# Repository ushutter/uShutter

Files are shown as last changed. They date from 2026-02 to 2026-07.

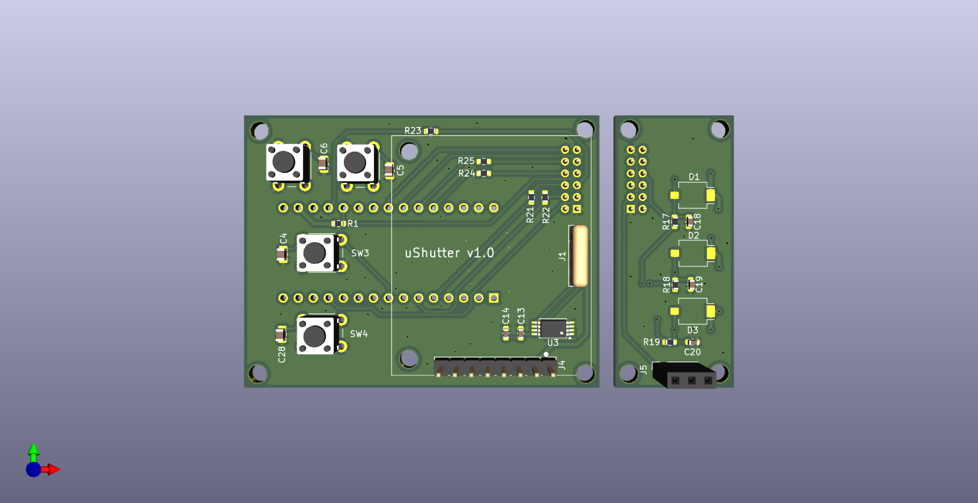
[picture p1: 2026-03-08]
Hardware/1.0.3/3D reveiw v1.0.3.png

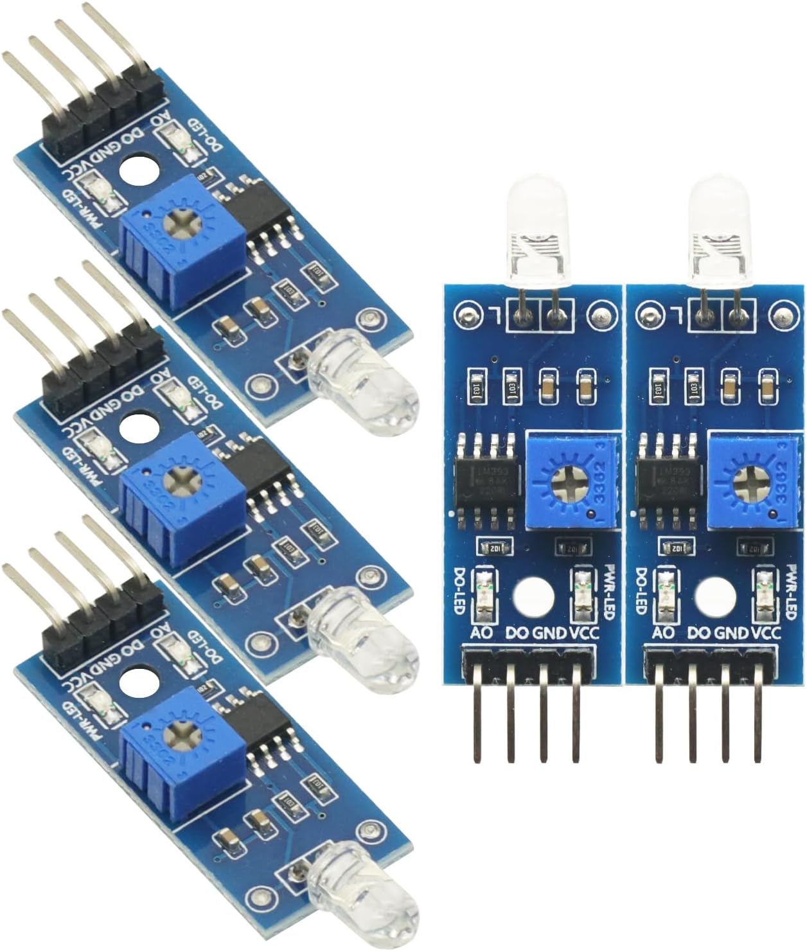
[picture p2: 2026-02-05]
Hardware/Preliminary Version/LM393_LED.jpg

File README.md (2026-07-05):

# uShutter

Introduction video on Youtube:
uShutter (https://www.youtube.com/watch?v=xxOWjmqUMyQ)
uShutter is an open, reproducible shutter timing specification and implementation, focused on time-domain shutter speed and curtain travel measurement.

uShutter provides a firmware and multiple reference hardware interface implementation for measuring:
* shutter exposure time and stability
* curtain travel time and stability

It uses pure time-domain signals from different optical sensors. Measurement accuracy highly depends on the sensors selected and PCB board manufacturing quality.

## What uShutter Is
* An open measurement core for shutter timing
* A reference implementation for single- and dual-sensor setups
* A stable timing interface others can implement or extend
* Suitable for DIY, education, analysis, and experimentation

## Core Capabilities (Open Scope)
uShutter includes the following open-source capabilities:
### Shutter Timing
* Optical trigger–based event capture
* Microsecond-resolution timestamps
* Direction-independent logic
### Single-Sensor Measurement
* Exposure duration measurement
* Multi-shot repeatability analysis
### Dual-Sensor Curtain Analysis
* Curtain travel time
* Relative curtain speed

## Hardware Philosophy
uShutter is designed to work with:
* Arduino / ATmega328P MCUs
* Simple optical sensors (e.g. LM393-based comparators)
* No specific sensor type, threshold method, or light source is assumed by the interface.

## Project Structure
/Firmware    Code implementation 

/Hardware    Reference schematics and layouts

[Theory, usage, and build notes](https://ushutter90.wordpress.com/how-to/)

## License
Firmware: Apache License 2.0

Hardware designs: CERN-OHL-S

This project is open by design and intent.

## Status
uShutter is under active development.

Interface stability and clarity take priority over feature expansion.

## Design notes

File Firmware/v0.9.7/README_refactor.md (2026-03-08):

# uShutter refactor notes (WIP)

This project has been split from a monolithic `.ino` into multiple translation units to improve maintainability and avoid Arduino preprocessor issues.

## File responsibilities

- `uShutter_v0_9_5_refactor_wip.ino`
  - Minimal Arduino entry placeholder.
  - Keep this tiny; do not put logic here.

- `app.cpp`
  - Main orchestration/state machine.
  - Setup/loop flow.
  - Measurement logic, stability calculation, button handling.
  - Calls into display and capture modules.

- `Display.h` / `Display.cpp`
  - OLED/UI rendering only.
  - Splash, error screen, realtime views, table view.
  - Should avoid business logic changes where possible.

- `Capture.h` / `Capture.cpp`
  - Interrupt attach/detach.
  - ISR edge capture and capture-complete signaling.
  - No UI rendering.

- `AppShared.h`
  - Shared enums/types/constants used across modules.
  - Single source for common declarations (`MeasureMode`, `SensorFrontend`, `TravelDirection`, `EdgeTimes`, sensor pin constants, etc.).

## Why this structure

Arduino `.ino` files are auto-preprocessed (prototype generation), which can break during aggressive function splitting. Keeping logic in `.cpp/.h` avoids those fragile transforms.

## Safe edit rules

1. **Prefer editing `.cpp/.h`, not `.ino`.**
2. **After each micro-change, compile immediately.**
3. **Keep cross-module contracts explicit:**
   - Put shared enums/structs in `AppShared.h`.
   - Keep module APIs in `Display.h` / `Capture.h`.
4. **Avoid duplicate type definitions** across modules.
5. **If introducing new shared state**, declare in `app.cpp`, reference via `extern` in module `.cpp` files.

## Compile check

Reference compile command:

```bash
arduino-cli compile --fqbn arduino:avr:nano /Users/leonyao/Documents/uShutter_v0_9_5_refactor_wip
```

Latest known good result (at time of writing):
- Flash: ~26,346 bytes (85%)
- RAM: ~1,396 bytes (68%)

## Next recommended refactor steps

1. Replace remaining broad `extern` usage with a thinner shared context struct (optional).
2. Move frontend detection helpers into a dedicated `Frontend.cpp/.h` (optional).
3. Add a small host-side smoke checklist (compile + key behavior sanity list).

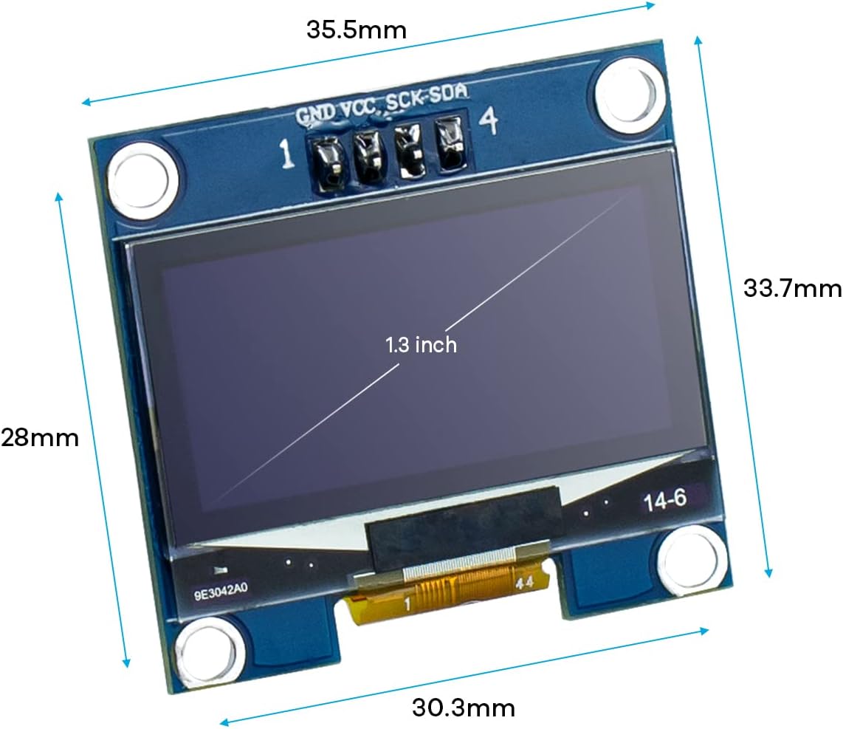
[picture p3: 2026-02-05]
Hardware/Preliminary Version/OLED.jpg

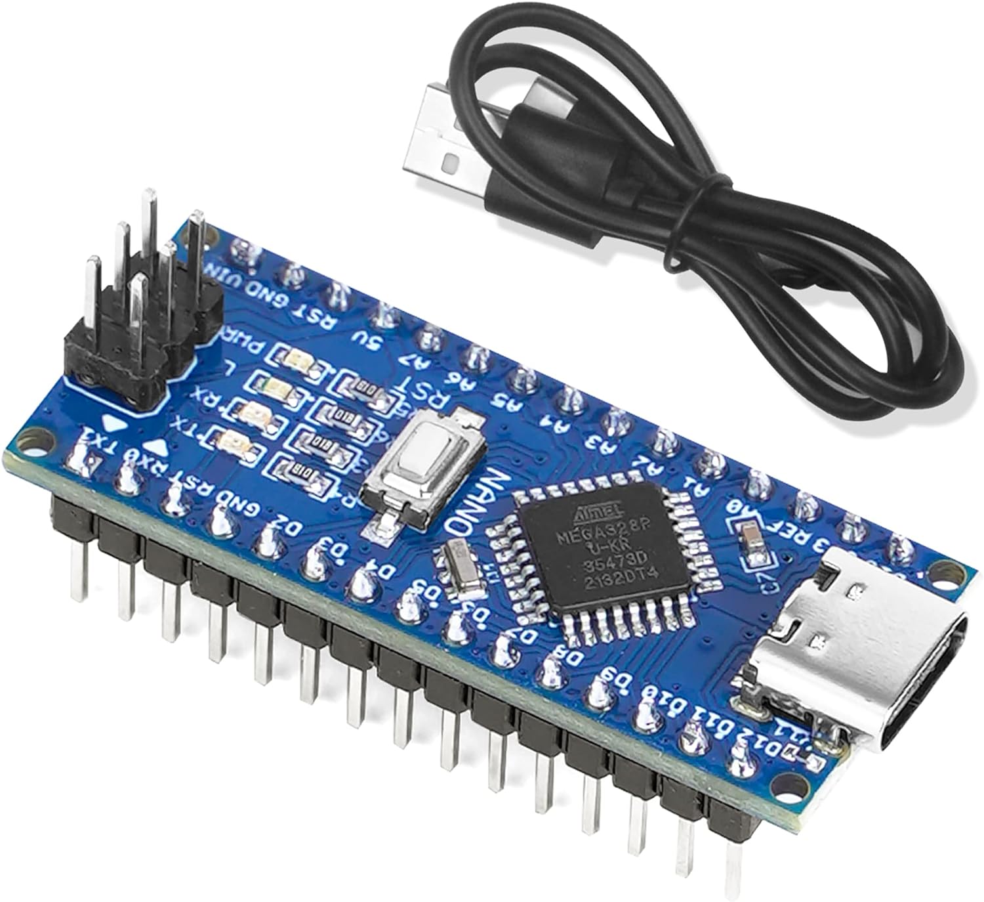
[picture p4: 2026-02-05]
Hardware/Preliminary Version/Arduino nano.jpg

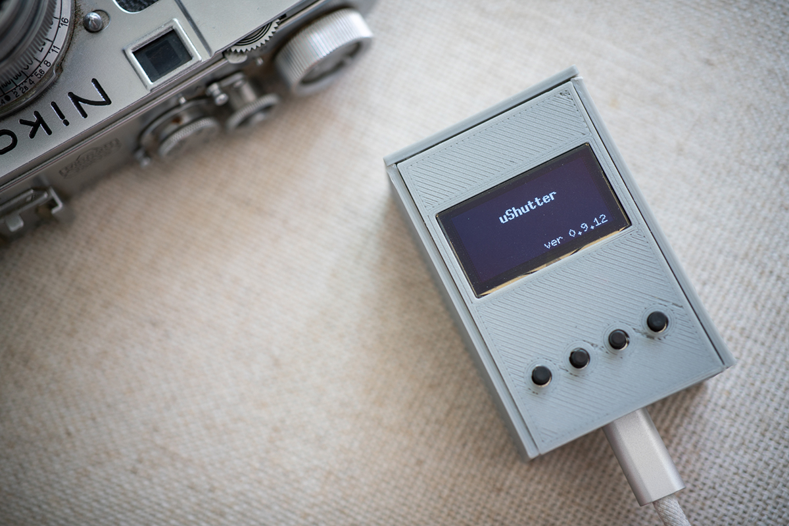
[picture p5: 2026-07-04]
Firmware/uShutter3.jpg

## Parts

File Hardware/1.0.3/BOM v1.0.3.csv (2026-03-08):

Id | Designator | Footprint | Quantity | Designation | Supplier and ref
1 | C6,C28,C5,C4 | C_0805_2012Metric | 4 | 10uF
2 | C14,C1,C16 | C_0603_1608Metric | 3 | 1uF
3 | R18,R19,R17 | R_0603_1608Metric | 3 | 100
4 | U3 | TSSOP-8_4.4x3mm_P0.65mm | 1 | AT24CS08-XHM
5 | D1,D3,D2 | Osram_BPW34S-SMD | 3 | BPW34-SMD
6 | J1 | R_Array_SIP4 | 1 | OLED
7 | R1 | R_0603_1608Metric | 1 | 100k
8 | R24,R25 | R_0603_1608Metric | 2 | 0
9 | R23,R22,R21,R28,R27,R29,R26 | R_0603_1608Metric | 7 | 22
10 | J5 | PinSocket_1x03_P2.54mm_Vertical | 1 | Light
11 | C13,C2,C17,C22 | C_0603_1608Metric | 4 | 0.1uF
12 | SW2,SW3,SW1,SW4 | SW_PUSH_6mm | 4 | SW_Push
13 | C19,C18,C20 | C_0603_1608Metric | 3 | 10pF or NC
14 | J4 | PinHeader_1x08_P2.54mm_Vertical | 1 | SPI
15 | C10,C9,C8 | C_0603_1608Metric | 3 | 10pF
16 | J3,J9 | ushutter | 2 | Conn_01x12
17 | R5,R6,R4 | R_0603_1608Metric | 3 | 220K
18 | R7,R8 | R_0603_1608Metric | 2 | 4.7K_or_depends_on_OLED
19 | R2 | R_0603_1608Metric | 1 | 1K
20 | A1 | Arduino_Nano | 1 | Arduino_Nano_v3.x
21 | U1 | SSOP-14_5.3x6.2mm_P0.65mm | 1 | 74HC14

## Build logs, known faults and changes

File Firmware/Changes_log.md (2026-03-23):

uShutter change summary: uShutter_v0_9_5_refactor_wip -> uShutter_v0_9_6
Generated: Fri Feb 27 22:52:08 PST 2026

== Files only in each folder ==
Only in v0_9_5_refactor_wip:
uShutter_v0_9_5_refactor_wip.ino

Only in v0_9_6:
uShutter_v0_9_6.ino

== High-level functional differences ==
- BTN_RESET pin changed to D4 in v0_9_6 (from D6 in refactor_wip at latest baseline).
- BTN_MODE pin remains D5, but behavior changed in v0_9_6:
  * short click: toggle sensor s1/s2 (only when FE=Dual and mode=SINGLE)
  * long hold: toggle mode DUAL<->SINGLE
- BTN_RESET behavior in v0_9_6 is single-click reset only.
- Startup splash flow remains 3-stage with 2.0s each splash.

== Key code-level diff snippets (app.cpp / Display.cpp / headers) ==
--- /Users/leonyao/Documents/uShutter/uShutter_v0_9_5_refactor_wip/app.cpp	2026-02-27 22:16:06
+++ /Users/leonyao/Documents/uShutter/uShutter_v0_9_6/app.cpp	2026-02-27 22:44:57
@@ -11,7 +11,7 @@
 // =================================================
 // Version
 // =================================================
-#define VERSION_STR "ver 0.9.5"
+#define VERSION_STR "ver 0.9.6"
 #define NAME "uShutter"
 #define SLOGAN ""
 
@@ -21,7 +21,8 @@
 #define MIN_VALID_EXPOSURE 1000     // Minimum valid exposure time (us)
 #define MAX_VALID_EXPOSURE 1500000  // Maximum valid exposure time (us)
 
-#define BTN_RESET 5            // Reset button pin (active-low)
+#define BTN_RESET 4            // Reset button pin (active-low)
+#define BTN_MODE 5
 #define BTN_DEBOUNCE_MS 50     // Button debounce time (ms)
 #define BTN_LONGPRESS_MS 1200  // Long press threshold (ms)
 
@@ -133,8 +134,9 @@
 volatile EdgeTimes s1 = { 0, 0, false };
 
 // Helpers for SINGLE mode sensor routing
+uint8_t single_mode_sensor = SINGLE_MODE_SENSOR;  // runtime: 1->s1, 2->s2
 bool singleUsesS1() {
-  return (SINGLE_MODE_SENSOR == 1);
+  return (single_mode_sensor == 1);
 }
 
 volatile bool new_result = false;
@@ -483,40 +485,71 @@
 bool handleResetButton() {
   static bool last_level = true;  // true = released (pull-up)
   static unsigned long t_last_change = 0;
-  static unsigned long t_pressed = 0;
-  static bool long_handled = false;
 
   bool level = digitalRead(BTN_RESET);  // HIGH released, LOW pressed
   unsigned long now_ms = millis();
 
   if (level != last_level) {
-    if (now_ms - t_last_change < BTN_DEBOUNCE_MS) {
-      return true;
+    if (now_ms - t_last_change < BTN_DEBOUNCE_MS) return true;
+    t_last_change = now_ms;
+    last_level = level;
+
+    // single click on release => reset
+    if (level) {
+      resetMeasurement();
     }
+    return true;
+  }
+  return false;
+}
+
+// BTN_MODE:
+// - Single click: toggle mode (DUAL<->SINGLE)
+// - Double click (only FE Dual + SINGLE mode): toggle single sensor s1/s2
+bool handleModeButton() {
+  static bool last_level = true;
+  static unsigned long t_last_change = 0;
+  static unsigned long t_pressed = 0;
+  static bool long_handled = false;
+
+  bool level = digitalRead(BTN_MODE);
+  unsigned long now_ms = millis();
+
+  bool sensor_toggle_enabled = (sensor_frontend == FRONTEND_FE1_DUAL && measure_mode == MODE_SINGLE_EXPOSURE);
+
+  if (level != last_level) {
+    if (now_ms - t_last_change < BTN_DEBOUNCE_MS) return true;
     t_last_change = now_ms;
     last_level = level;
 
     if (!level) {
+      // pressed
       t_pressed = now_ms;
       long_handled = false;
     } else {
+      // released
       if (!long_handled) {
-        resetMeasurement();
+        // short click: toggle sensor s1/s2 (only when FE=Dual and mode=SINGLE)
+        if (sensor_toggle_enabled) {
+          single_mode_sensor = (single_mode_sensor == 1) ? 2 : 1;
+          disableLightISR();
+          displayModeSplash();
+          delay(600);
+          resetMeasurement();
+        }
       }
     }
     return true;
   }
 
+  // long press: toggle mode
   if (!level && !long_handled) {
     if (now_ms - t_pressed >= BTN_LONGPRESS_MS) {
       long_handled = true;
-
       measure_mode = (measure_mode == MODE_DUAL_CURTAIN) ? MODE_SINGLE_EXPOSURE : MODE_DUAL_CURTAIN;
-
       disableLightISR();
       displayModeSplash();
       delay(600);
-
       resetMeasurement();
       return true;
     }
@@ -525,6 +558,7 @@
   return false;
 }
 
+
 // =================================================
 // SETUP
 // =================================================
@@ -540,6 +574,7 @@
 
   configureSensorFrontend();
   pinMode(BTN_RESET, INPUT_PULLUP);
+  pinMode(BTN_MODE, INPUT_PULLUP);
 
   u8g2.begin();
 
@@ -570,6 +605,7 @@
 // =================================================
 void loop() {
   handleResetButton();
+  handleModeButton();
 
   if (ui_state == UI_ERROR) {
     displayErrorCode(error_code);

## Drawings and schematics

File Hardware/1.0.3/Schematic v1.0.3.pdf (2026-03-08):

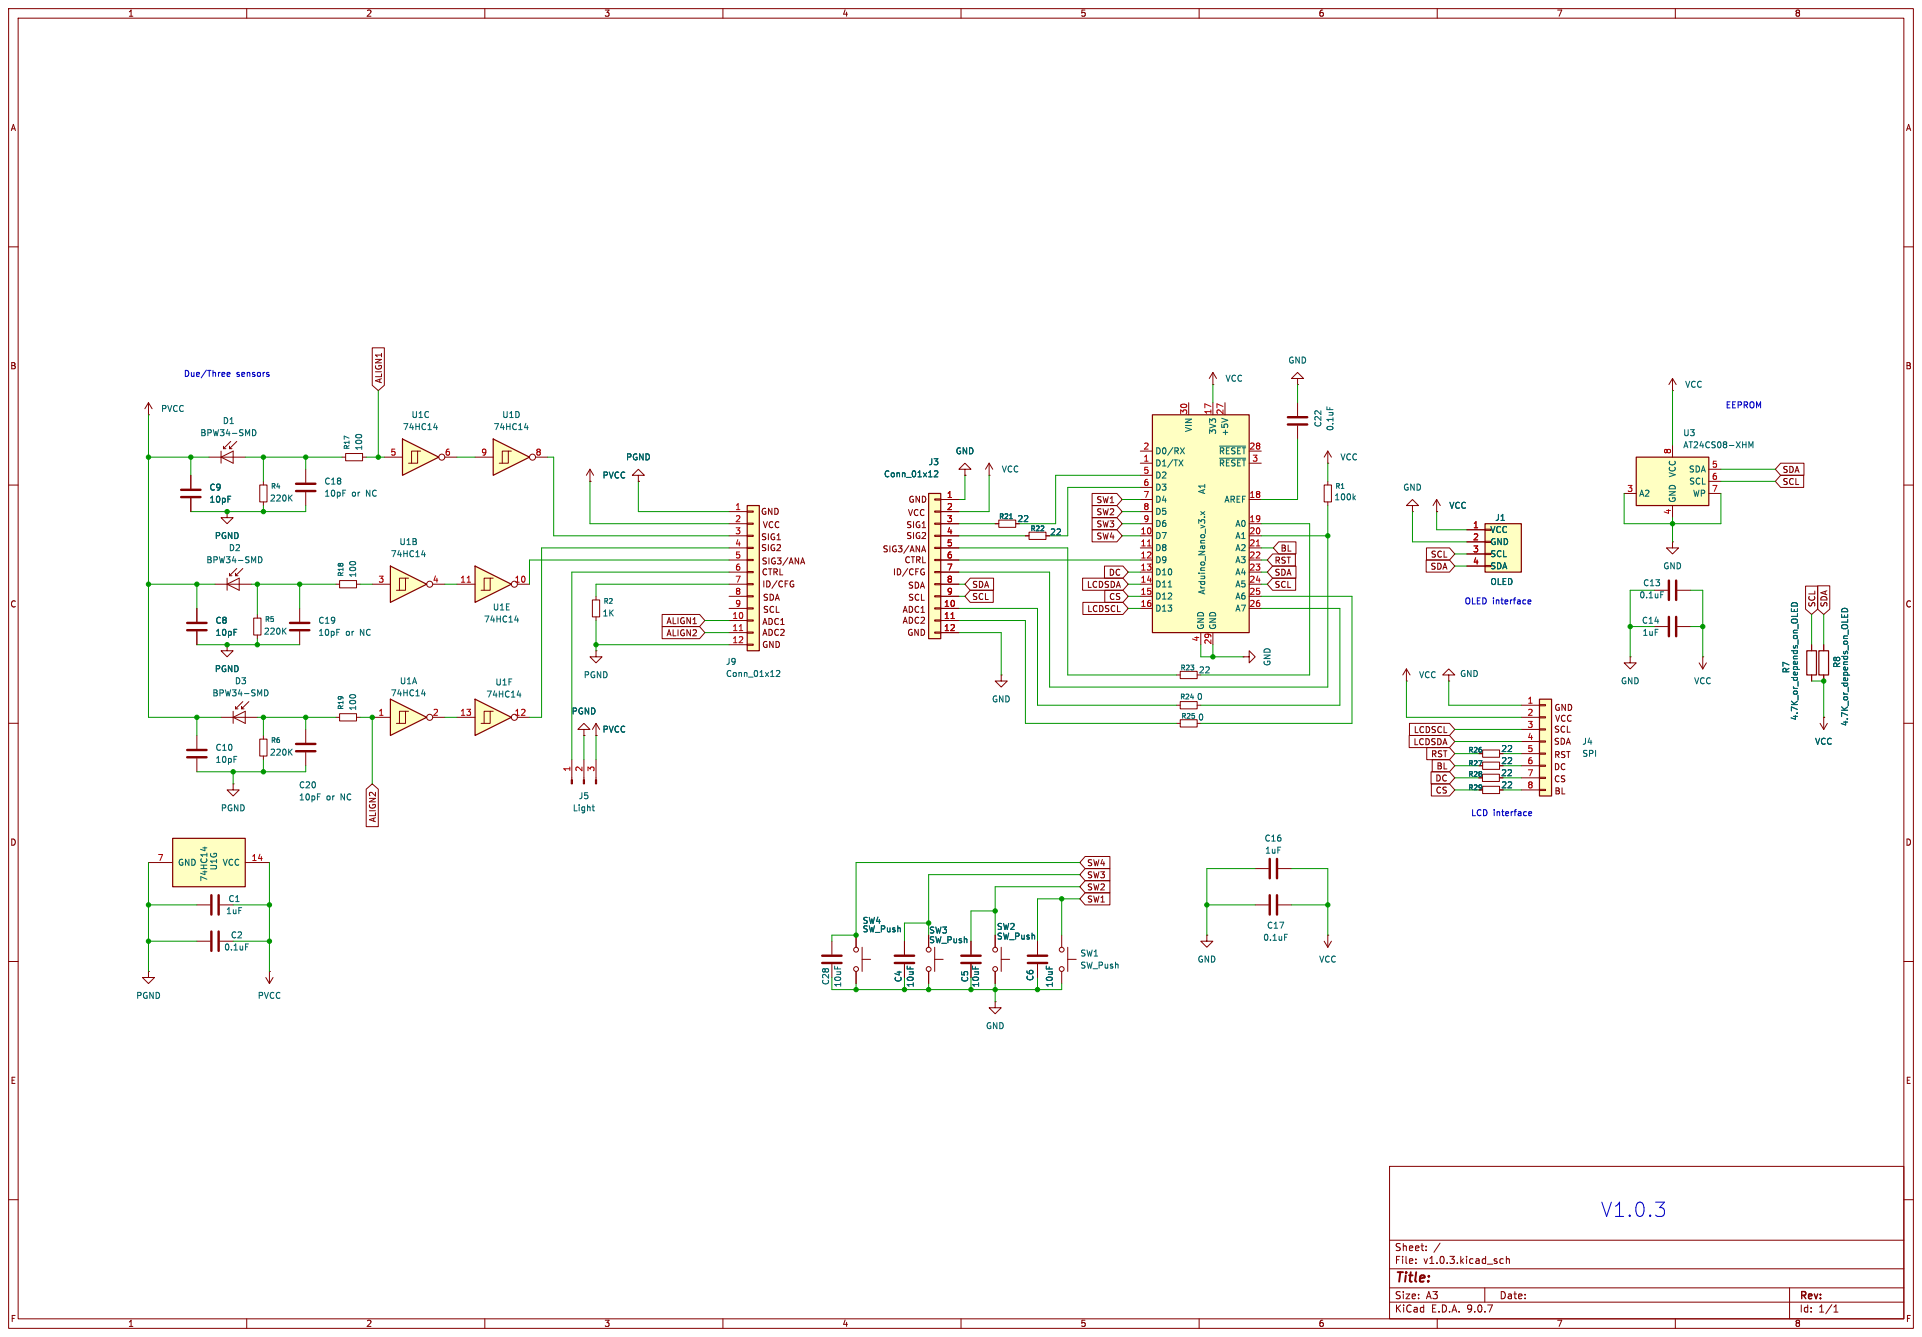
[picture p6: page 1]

Id: 1/1 Title: File: v1.0.3.kicad_sch Sheet: /

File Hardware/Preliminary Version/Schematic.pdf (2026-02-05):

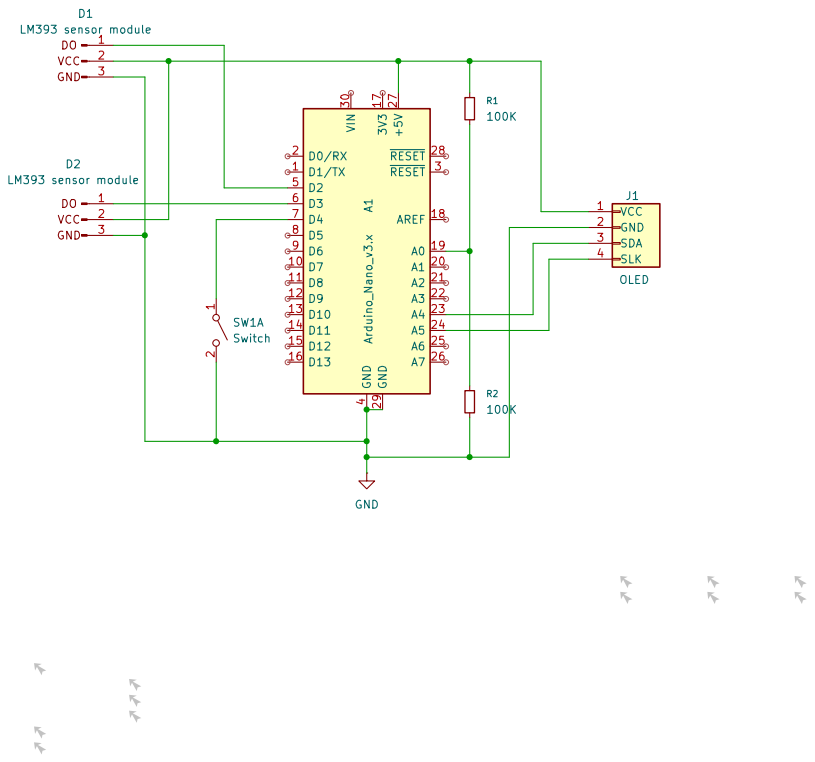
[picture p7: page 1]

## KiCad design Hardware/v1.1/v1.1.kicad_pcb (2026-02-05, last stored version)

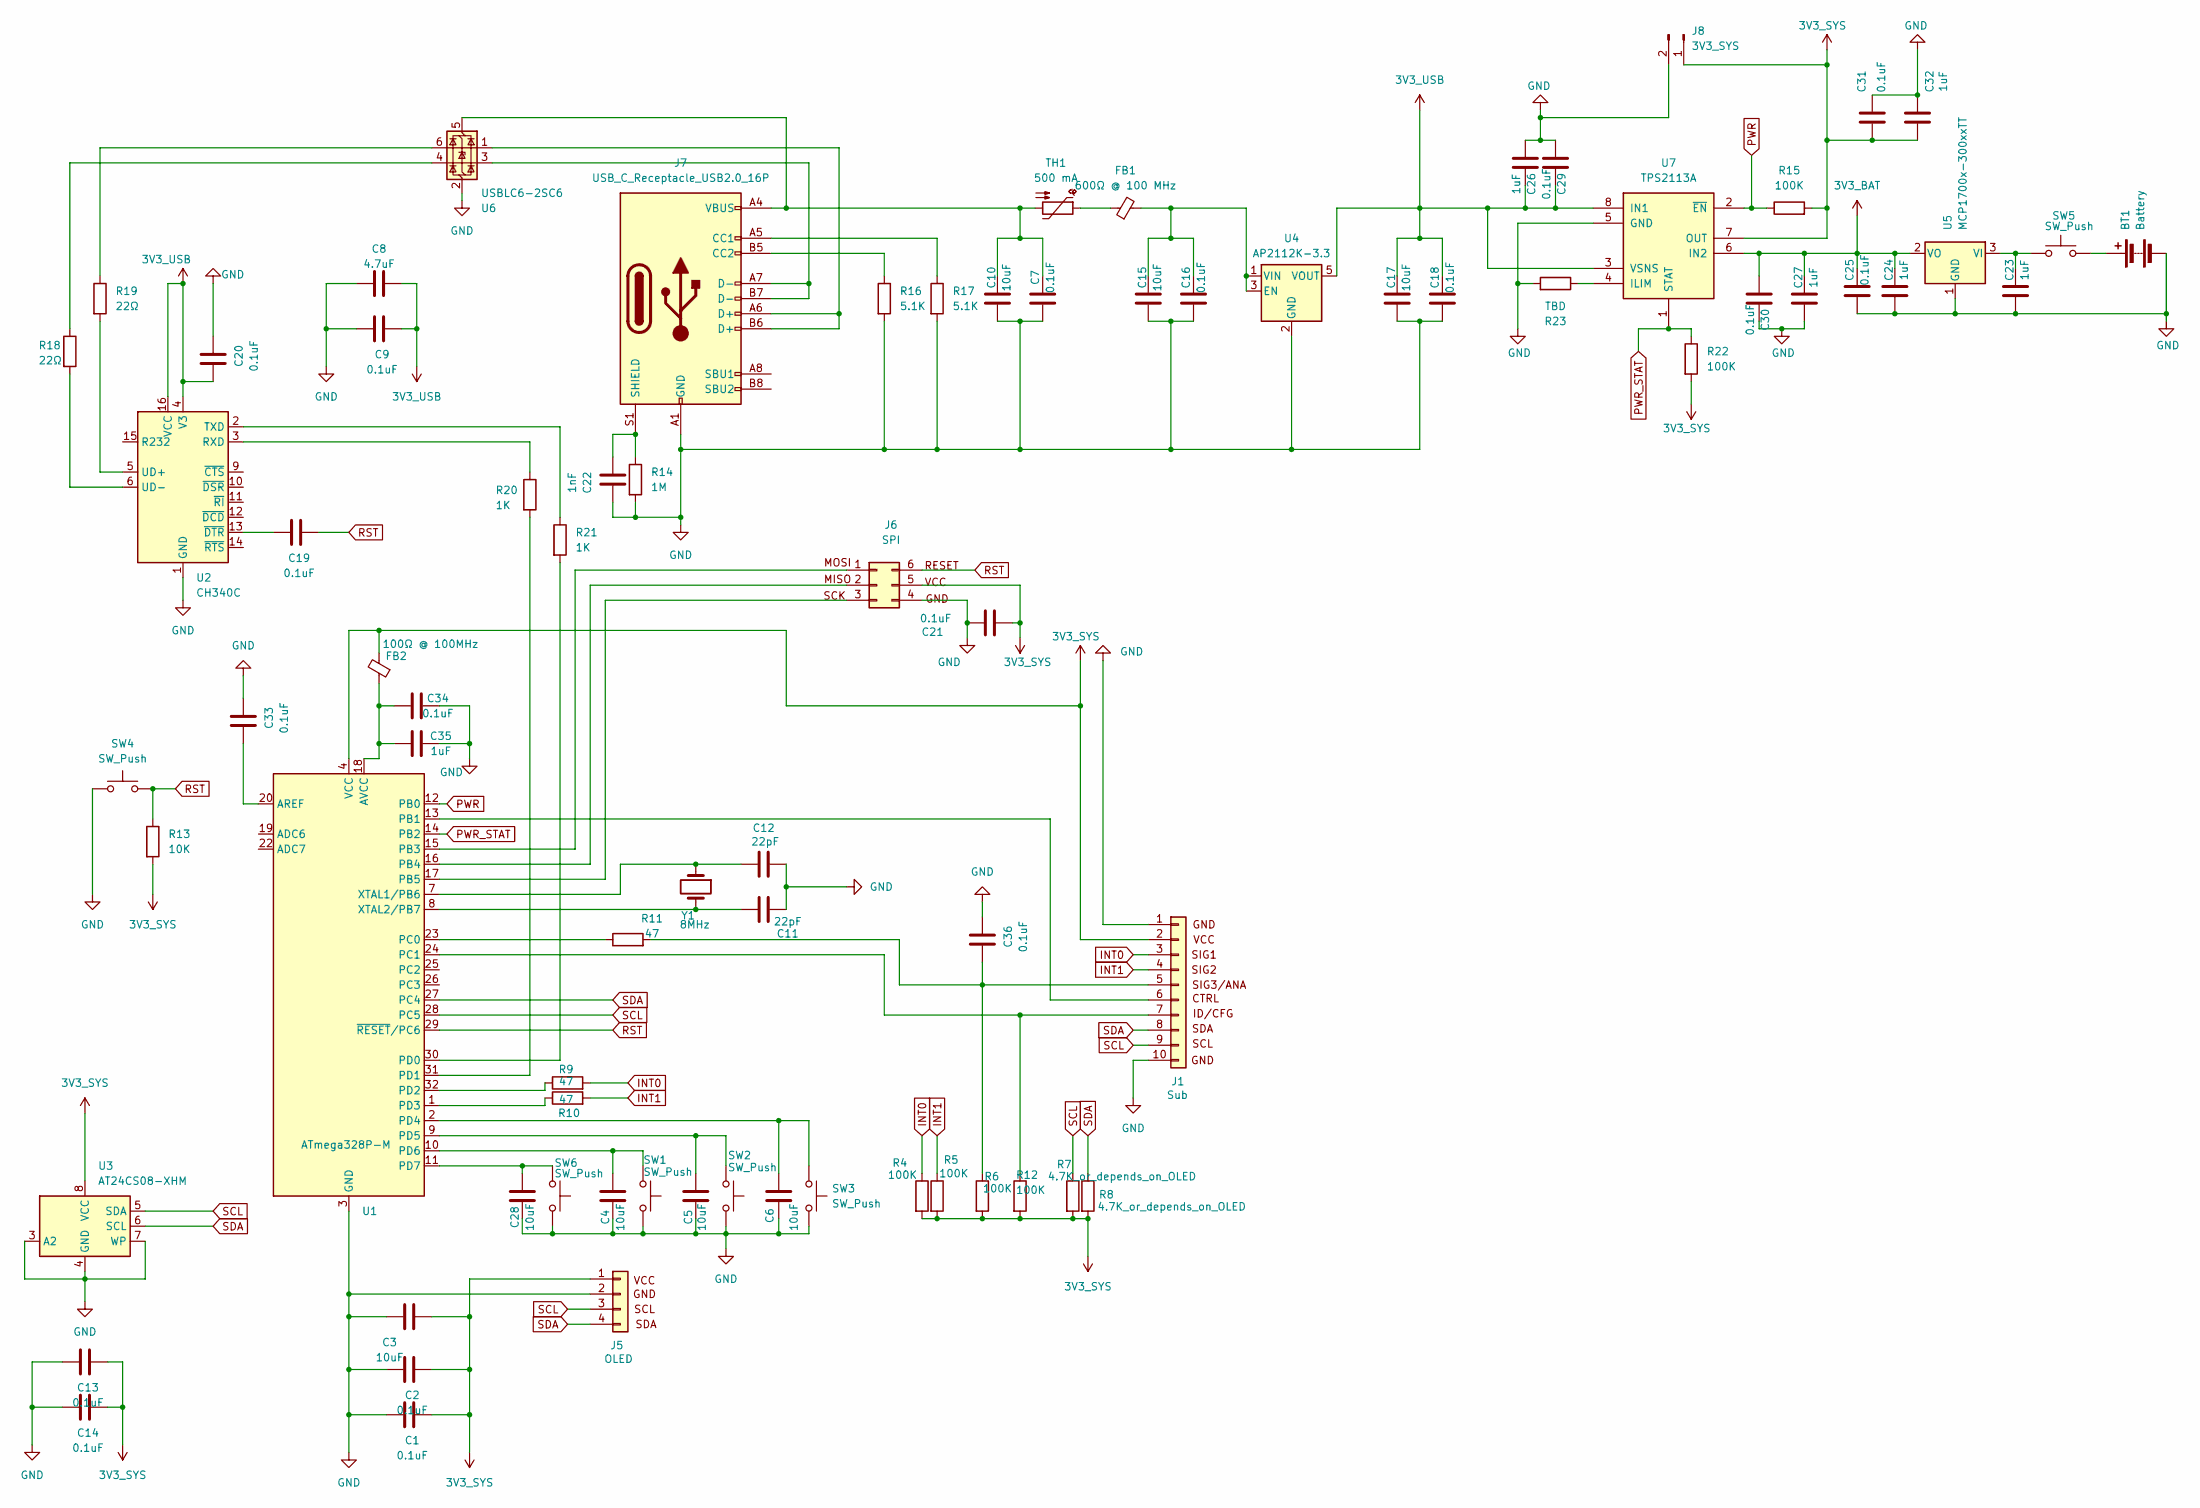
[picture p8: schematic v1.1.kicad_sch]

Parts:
BT1: Battery; PinHeader_1x02_P2.54mm_Vertical
C1, C2, C7, C9, C13, C14, C16, C18, C19, C20, C21, C25, C29, C30, C31, C33, C34, C36: 0.1uF; C_0603_1608Metric
C3, C4, C5, C6, C10, C15, C17, C28: 10uF; C_0805_2012Metric
C8: 4.7uF; C_0603_1608Metric
C11, C12: 22pF; C_0603_1608Metric
C22: 1nF; C_0603_1608Metric
C23, C24, C26, C27, C32, C35: 1uF; C_0603_1608Metric
FB1: 600Ω @ 100 MHz; L_0603_1608Metric
FB2: 100Ω @ 100MHz; L_0603_1608Metric
J1: Sub; PinSocket_2x05_P2.54mm_Vertical
J5: OLED; PinSocket_1x04_P2.54mm_Vertical
J6: SPI; PinSocket_2x03_P2.54mm_Vertical
J7: USB_C_Receptacle_USB2.0_16P; USB_C_Receptacle_Palconn_UTC16-G
J8: 3V3_SYS; PinHeader_1x02_P2.54mm_Vertical
R4, R5, R6, R12, R15, R22: 100K; R_0603_1608Metric
R7, R8: 4.7K_or_depends_on_OLED; R_0603_1608Metric
R9, R10, R11: 47; R_0603_1608Metric
R13: 10K; R_0603_1608Metric
R14: 1M; R_0603_1608Metric
R16, R17: 5.1K; R_0603_1608Metric
R18, R19: 22Ω; R_0603_1608Metric
R20, R21: 1K; R_0603_1608Metric
R23: TBD; R_0603_1608Metric
SW1, SW2, SW3, SW6: SW_Push; SW_PUSH_6mm
SW4, SW5: SW_Push; PinHeader_1x02_P2.54mm_Vertical
TH1: 500 mA; Fuse_1206_3216Metric
U1: ATmega328P-M; TQFP-32_7x7mm_P0.8mm
U2: CH340C; SOP-16_4.4x10.4mm_P1.27mm
U3: AT24CS08-XHM; TSSOP-8_4.4x3mm_P0.65mm
U4: AP2112K-3.3; SOT-23-5
U5: MCP1700x-300xxTT; SOT-23
U6: USBLC6-2SC6; SOT-23-6
U7: TPS2113A; TSSOP-8_4.4x3mm_P0.65mm
Y1: 8MHz; Crystal_SMD_5032-2Pin_5.0x3.2mm

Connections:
3V3_BAT: C24.2, C25.2, C27.2, C30.1, U5.2 (VO), U7.6 (IN2)
3V3_SYS: C1.2, C2.2, C3.2, C13.2, C14.2, C21.1, C31.2, C32.1, FB2.2, J1.2, J5.1, J6.5, J8.1, R4.2, R5.2, R6.2, R7.2, R8.2, R12.2, R13.2, R15.2, R22.2, U1.4 (VCC), U1.6 (VCC), U3.8 (VCC), U7.7 (OUT)
3V3_USB: C8.2, C9.2, C17.2, C18.2, C20.1, C26.2, C29.2, U2.4 (V3), U2.16 (VCC), U4.5 (VOUT), U7.3 (VSNS), U7.8 (IN1)
GND: BT1.2 (-), C1.1, C2.1, C3.1, C4.2, C5.2, C6.2, C7.1, C8.1, C9.1, C10.1, C11.2, C12.2, C13.1, C14.1, C15.1, C16.1, C17.1, C18.1, C20.2, C21.2, C22.2, C23.1, C24.1, C25.1, C26.1, C27.1, C28.2, C29.1, C30.2, C31.1, C32.2, C33.2, C34.2, C35.2, C36.2, J1.1, J1.10, J5.2, J6.4, J7.A1 (GND), J7.A12 (GND), J7.B1 (GND), J7.B12 (GND), J8.2, R14.2, R16.2, R17.2, R23.2, SW1.2, SW2.2, SW3.2, SW4.1, SW6.2, U1.3 (GND), U1.5 (GND), U1.21 (GND), U1.33 (GND), U2.1 (GND), U3.3 (A2), U3.4 (GND), U3.7 (WP), U4.2 (GND), U5.1 (GND), U6.2 (GND), U7.5 (GND)
INT0: J1.3, R4.1, R9.2
INT1: J1.4, R5.1, R10.2
unnamed: BT1.1 (+), SW5.2
unnamed: FB1.1, TH1.1
unnamed: C36.1, J1.5, R6.1, R11.2
unnamed: J1.6, U1.13 (PB1)
unnamed: J1.7, R12.1, U1.24 (PC1)
unnamed: J6.1, U1.15 (PB3)
unnamed: J6.2, U1.16 (PB4)
unnamed: J6.3, U1.17 (PB5)
unnamed: J7.A5 (CC1), R17.1
unnamed: J7.B5 (CC2), R16.1
unnamed: J7.A6 (D+), J7.B6 (D+), U6.1 (I/O1)
unnamed: J7.A7 (D-), J7.B7 (D-), U6.3 (I/O2)
unnamed: C22.1, J7.S1 (SHIELD), R14.1
unnamed: R18.1, U6.4 (I/O2)
unnamed: R19.1, U6.6 (I/O1)
unnamed: C33.1, U1.20 (AREF)
unnamed: C34.1, C35.1, FB2.1, U1.18 (AVCC)
unnamed: R11.1, U1.23 (PC0)
unnamed: R21.2, U1.30 (PD0)
unnamed: R20.2, U1.31 (PD1)
unnamed: R9.1, U1.32 (PD2)
unnamed: R10.1, U1.1 (PD3)
unnamed: C6.1, SW3.1, U1.2 (PD4)
unnamed: C5.1, SW2.1, U1.9 (PD5)
unnamed: C4.1, SW1.1, U1.10 (PD6)
unnamed: C28.1, SW6.1, U1.11 (PD7)
unnamed: C12.1, U1.7 (XTAL1/PB6), Y1.1
unnamed: C11.1, U1.8 (XTAL2/PB7), Y1.2
unnamed: R20.1, U2.3 (RXD)
unnamed: R21.1, U2.2 (TXD)
unnamed: R19.2, U2.5 (UD+)
unnamed: R18.2, U2.6 (UD-)
unnamed: C19.1, U2.13 (~DTR)
unnamed: C15.2, C16.2, FB1.2, U4.1 (VIN), U4.3 (EN)
unnamed: C23.2, SW5.1, U5.3 (VI)
unnamed: C7.2, C10.2, J7.A4 (VBUS), J7.A9 (VBUS), J7.B4 (VBUS), J7.B9 (VBUS), TH1.2, U6.5 (VBUS)
unnamed: R23.1, U7.4 (ILIM)
PWR: R15.1, U1.12 (PB0), U7.2 (~EN)
PWR_STAT: R22.1, U1.14 (PB2), U7.1 (STAT)
RST: C19.2, J6.6, R13.1, SW4.2, U1.29 (~RESET/PC6)
SCL: J1.9, J5.3, R7.1, U1.28 (PC5), U3.5 (SDA)
SDA: J1.8, J5.4, R8.1, U1.27 (PC4), U3.6 (SCL)

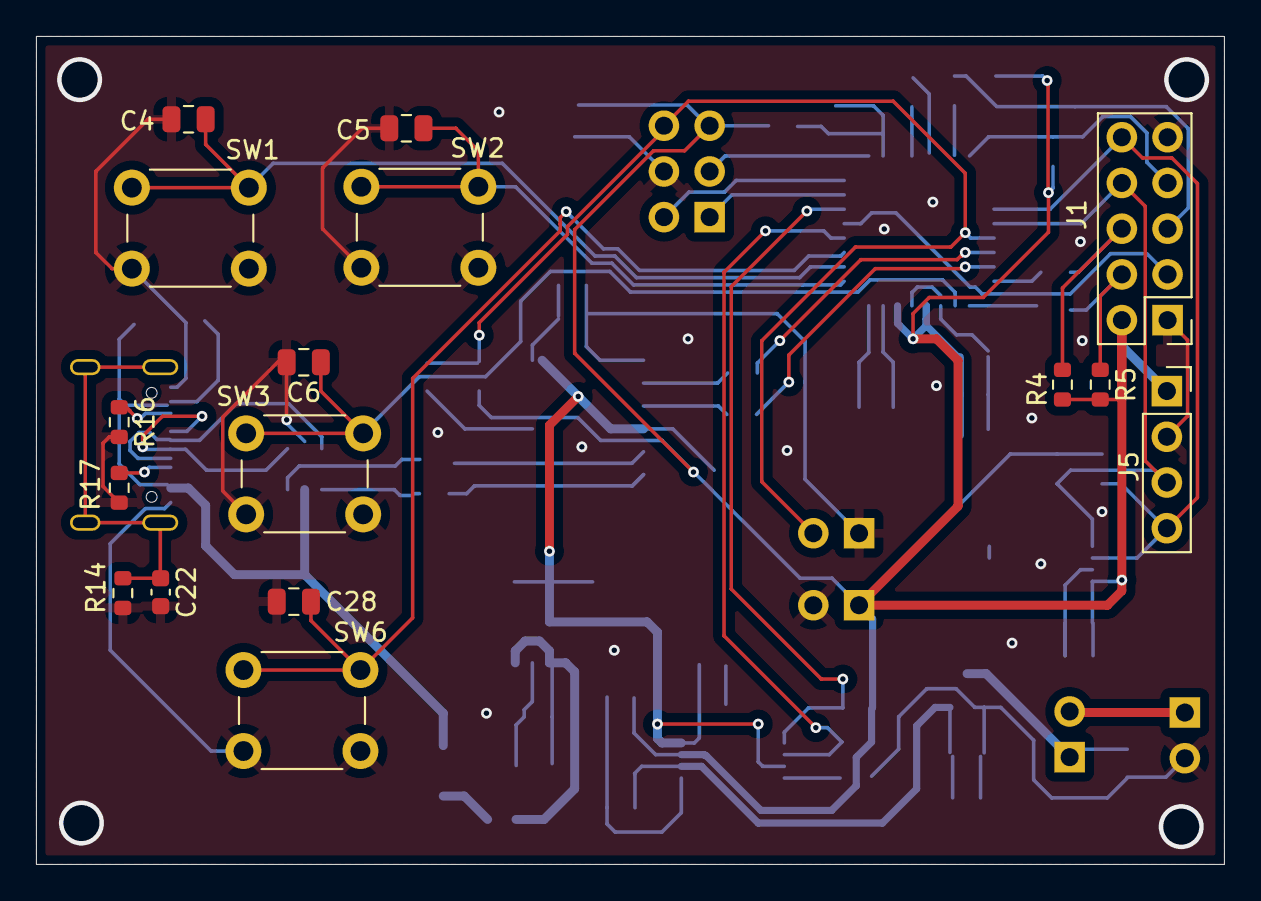
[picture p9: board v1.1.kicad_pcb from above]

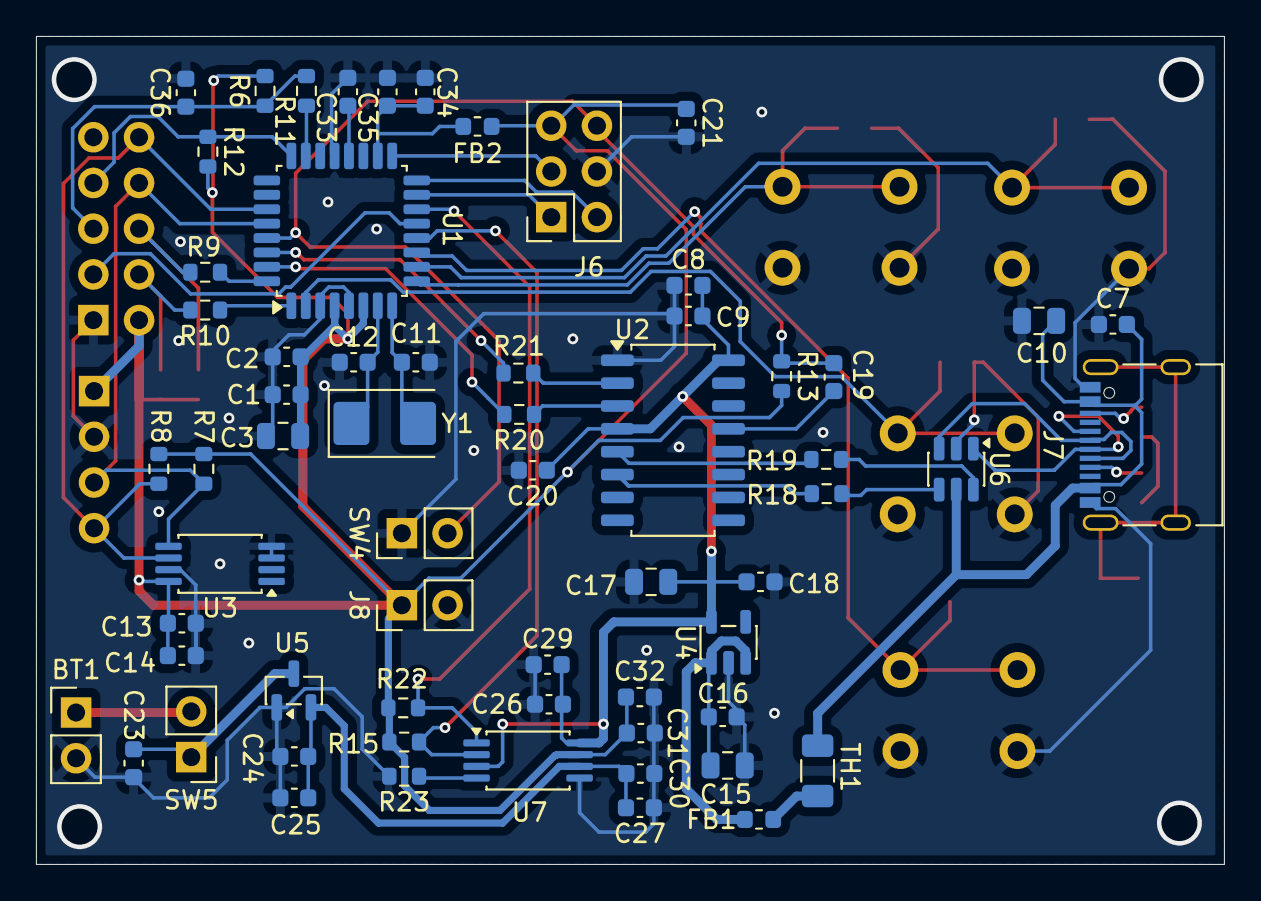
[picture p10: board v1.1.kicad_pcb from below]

Board: 2 copper layers, 66.0 x 46.0 mm, 79 parts (63 on the bottom side), 48 nets.

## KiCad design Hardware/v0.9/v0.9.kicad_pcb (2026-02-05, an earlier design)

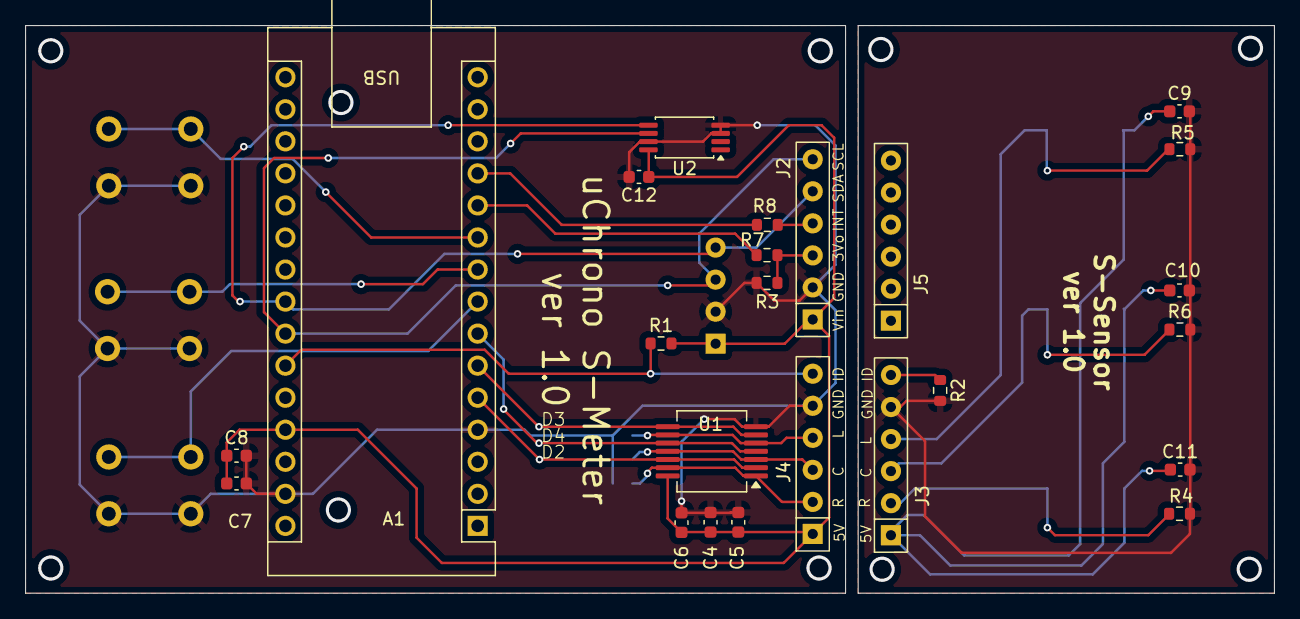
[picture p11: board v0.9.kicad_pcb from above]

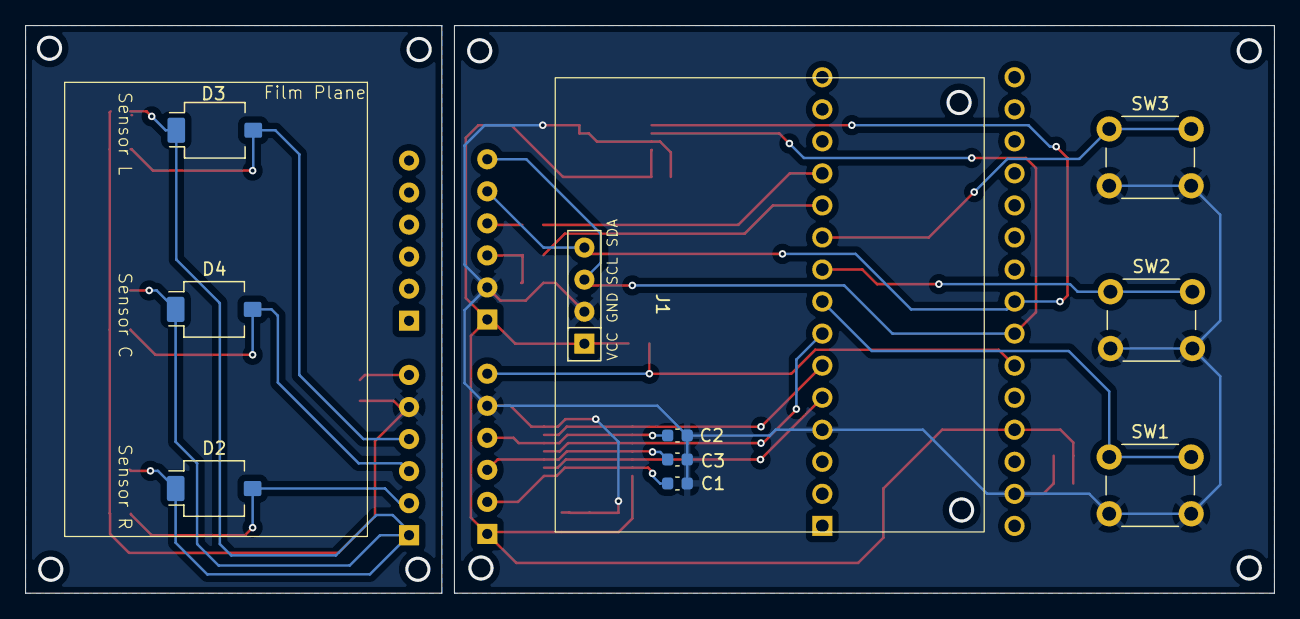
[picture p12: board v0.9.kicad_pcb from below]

Board: 2 copper layers, 99.0 x 45.0 mm, 34 parts (10 on the bottom side), 24 nets.

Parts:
A1: Arduino_Nano_v3.x; Arduino_Nano
C1, C2, C3: 100pF; C_0603_1608Metric
C4, C6, C7, C12: 0.1uF; C_0603_1608Metric
C5, C8: 10uF; C_0603_1608Metric
C9, C10, C11: 4.7pF; C_0603_1608Metric
D2, D3, D4: BPW34-SMD; Osram_BPW34S-SMD
J1: OLED; R_Array_SIP4
J2, J5: TSL2591; R_Array_SIP6
J3, J4: Jumper; R_Array_SIP6
R1, R3: 100k; R_0603_1608Metric
R2, R4, R5, R6: 47k; R_0603_1608Metric
R7: 1k; R_0603_1608Metric
R8: 0; R_0603_1608Metric
SW1, SW2, SW3: SW_MEC_5E; SW_PUSH_6mm
U1: 74HC14; SSOP-14_5.3x6.2mm_P0.65mm
U2: AT24CS08-XHM; TSSOP-8_4.4x3mm_P0.65mm

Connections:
GND: A1.4 (GND), A1.29 (GND), C1.2, C2.2, C3.2, C4.2, C5.2, C6.2, C7.2, C8.2, C12.2, J1.2 (GND), J2.2 (GND), J4.5, R3.1, SW1.2, SW2.2, SW3.2, U1.7 (GND), U2.3 (A2), U2.4 (GND), U2.7 (WP)
unnamed: A1.27 (+5V), C4.1, C5.1, C6.1, C7.1, C8.1, C12.1, J1.1 (VCC), J2.1 (Vin), J4.1, R1.2, U1.14 (VCC), U2.8 (VCC)
unnamed: A1.23 (A4), J1.4 (SDA), J2.5 (SDA), U2.5 (SDA)
unnamed: A1.24 (A5), J1.3 (SCK), J2.6 (SCL), U2.6 (SCL)
unnamed: A1.25 (A6), J4.6, R1.1
unnamed: A1.5 (D2), U1.2, U1.12
unnamed: A1.6 (D3), U1.6, U1.8
unnamed: A1.7 (D4), U1.4, U1.10
unnamed: A1.8 (D5), SW1.1
unnamed: A1.9 (D6), SW2.1
unnamed: A1.10 (D7), SW3.1
unnamed: A1.11 (D8), R7.2
unnamed: A1.12 (D9), R8.2
unnamed: D2.2 (A), J3.2, R4.2
unnamed: C9.1, C10.1, C11.1, D2.1 (K), D3.1 (K), D4.1 (K), J3.1
unnamed: D3.2 (A), J3.3, R5.1
unnamed: D4.2 (A), J3.4, R6.1
unnamed: J2.3 (3Vo), R3.2, R7.1
unnamed: J2.4 (Int), R8.1
unnamed: C9.2, C10.2, C11.2, J3.5, R2.2, R4.1, R5.2, R6.2
unnamed: J3.6, R2.1
unnamed: C1.1, J4.2, U1.1, U1.13
unnamed: C2.1, J4.3, U1.5, U1.9
unnamed: C3.1, J4.4, U1.3, U1.11

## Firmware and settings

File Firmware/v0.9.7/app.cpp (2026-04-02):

// app.cpp
// Orchestration/state machine/main loop for uShutter.
// Display and capture internals are split into Display.* and Capture.*

#include <Arduino.h>
#include <U8g2lib.h>
#include <Wire.h>
#include <math.h>
#include "AppShared.h"

// =================================================
// Version
// =================================================
#define VERSION_STR "ver 0.9.7"
#define NAME "uShutter"
#define SLOGAN ""

// =================================================
// Parameters
// =================================================
#define MIN_VALID_EXPOSURE 1000     // Minimum valid exposure time (us)
#define MAX_VALID_EXPOSURE 1500000  // Maximum valid exposure time (us)

#define BTN_RESET 4            // Reset button pin (active-low)
#define BTN_MODE 5
#define CTRL 9
#define ADC1 A7
#define ADC2 A6
#define BTN_DEBOUNCE_MS 50     // Button debounce time (ms)
#define BTN_LONGPRESS_MS 1200  // Long press threshold (ms)

#define STABLE_TOLERANCE_PERCENT 10.0  // Stability threshold (%), compared against stability_percent (CV%)

#define MATCH_THRESHOLD_PERMILLE 150  // 15% threshold for standard shutter match

// Dual-capture timeout: if a capture starts but doesn't complete -> ERROR
#define CAPTURE_TIMEOUT_US 300000UL  // 300ms (tune if needed)

// CTRL drives AO3400A gate for LED light source
#define LIGHT_CTRL_ACTIVE_HIGH 1

// Default mode:
MeasureMode measure_mode = MODE_DUAL_CURTAIN;

// =================================================
// SINGLE mode sensor selection (compile-time)
//
// To avoid ambiguity, choose which physical sensor is used for
// MODE_SINGLE_EXPOSURE.
//
//   1 -> use s1 (SENSOR_B / D3)
//   2 -> use s2 (SENSOR_A / D2)
//
// Default below matches your current usage (single mode uses s1).
// =================================================
#define SINGLE_MODE_SENSOR 1

// =================================================
// Frontend auto-detect via A1
// Hardware requirement:
// - Use ONE fixed pull-up on A1 to VCC: 10k (external resistor)
// - Each frontend selects one pulldown to GND:
//     FE1 = 1k   -> map to Dual
//     FE2 = 2.2k -> map to Single
//     FE3 = 4.7k -> reserved
//     FE4 = 10k  -> reserved

#define FRONTEND_DETECT_PIN A1

// ADC bucket thresholds for 10k pull-up scheme (10-bit ADC)
//   adc < 140          -> FE1 (1k)    -> Dual
//   140 <= adc < 255   -> FE2 (2.2k)  -> Single
//   255 <= adc < 420   -> FE3 (4.7k)  -> Reserved
//   adc >= 420         -> FE4 (10k)   -> Reserved
#define DETECT_TH_FE1_MAX 140
#define DETECT_TH_FE2_MAX 255
#define DETECT_TH_FE3_MAX 420
#define FRONTEND_DEBUG_SERIAL 1

// If you want to force a type, set to 1.
// Otherwise, auto-detect from A1 at boot.
#define FRONTEND_FORCE_MANUAL 0
SensorFrontend sensor_frontend = FRONTEND_FE1_DUAL;

// Polarity: active_low=true means LOW = shutter open/light detected
const bool active_low = true;


static inline void setLightSource(bool on) {
#if LIGHT_CTRL_ACTIVE_HIGH
  digitalWrite(CTRL, on ? HIGH : LOW);
#else
  digitalWrite(CTRL, on ? LOW : HIGH);
#endif
}

// Edge glitch filter (us). Single/Dual frontend paths are digital and usually clean.
volatile uint16_t MIN_EDGE_SPACING_US = 0;

// =================================================
// OLED (page buffer)
// =================================================
U8G2_SH1106_128X64_NONAME_1_HW_I2C u8g2(U8G2_R0);

// =================================================
// UI State machine
// =================================================
enum UIState { UI_READY,
               UI_MEASURING,
               UI_HOLD,
               UI_UNSTABLE,
               UI_ERROR };
UIState ui_state = UI_READY;
bool alignment_mode = false;

uint8_t error_code = 0;  // E01..E05

volatile TravelDirection last_dir = DIR_UNKNOWN;

// =================================================
// Standard shutter speeds (PROGMEM)
// =================================================
const uint16_t shutter_denoms[] PROGMEM = {
  1000, 500, 400, 250, 200, 125, 100, 60, 50, 30,
  25, 15, 10, 8, 5, 4, 2, 1
};

const char shutter_labels[][8] PROGMEM = {
  "1/1000", "1/500", "1/400", "1/250", "1/200",
  "1/125", "1/100", "1/60", "1/50", "1/30",
  "1/25", "1/15", "1/10", "1/8", "1/5",
  "1/4", "1/2", "1\""
};

#define SHUTTER_COUNT (sizeof(shutter_denoms) / sizeof(uint16_t))

// =================================================
// Global display buffers
// =================================================
char g_label[16];
char g_buf[32];
char g_tmp[20];

// =================================================
// Edge capture (per sensor)
// =================================================

// Rename: sA -> s2, sB -> s1
volatile EdgeTimes s2 = { 0, 0, false };
volatile EdgeTimes s1 = { 0, 0, false };

// Helpers for SINGLE mode sensor routing
uint8_t single_mode_sensor = SINGLE_MODE_SENSOR;  // runtime: 1->s1, 2->s2
bool singleUsesS1() {
  return (single_mode_sensor == 1);
}

volatile bool new_result = false;
volatile bool capture_done = false;

// Capture start tracking (for timeout)
volatile bool capture_started = false;
volatile unsigned long capture_start_us = 0;

// Edge spacing filter state
volatile unsigned long last_edge_s2_us = 0;
volatile unsigned long last_edge_s1_us = 0;

// Idle level sampling (used for polarity-agnostic edge capture)
bool idle_high_s2 = true;
bool idle_high_s1 = true;

// =================================================
// History buffers (per shot)
// NOTE: Keeping expA_hist/expB_hist naming to reduce churn,
// but conceptually expA=exp_s2, expB=exp_s1
// =================================================
unsigned long expA_hist[STABLE_COUNT];  // s2 exposure
unsigned long expB_hist[STABLE_COUNT];  // s1 exposure

unsigned long travel1_hist[STABLE_COUNT];  // abs(delta open)
unsigned long travel2_hist[STABLE_COUNT];  // abs(delta close)

int16_t errA_hist[STABLE_COUNT];  // s2 error
int16_t errB_hist[STABLE_COUNT];  // s1 error

uint8_t hist_index = 0;
uint8_t hist_filled = 0;

// Stability metrics (all are CV%)
// - Single mode: stability_percent == cv_exp_s2_percent
// - Dual mode  : stability_percent == max(cv_v1_percent, cv_v2_percent)
float stability_percent = 0.0f;
float cv_exp_s2_percent = 0.0f;
float cv_v1_percent = 0.0f;
float cv_v2_percent = 0.0f;

// =================================================
// Frontend detect (A1)
// =================================================
static uint16_t readAdcMedian(uint8_t pin, uint8_t n = 16) {
  pinMode(pin, INPUT_PULLUP);

  // Let the divider settle
  delay(50);

  // Dummy reads to flush ADC S/H capacitor history
  analogRead(pin);
  delay(2);
  analogRead(pin);
  delay(2);
  analogRead(pin);
  delay(2);

  // Collect n samples
  uint16_t v[n];
  for (int i = 0; i < n; i++) {
    v[i] = analogRead(pin);
    delay(2);
  }

  // Sort (small n => simple sort)
  for (int i = 0; i < n; i++) {
    for (int j = i + 1; j < n; j++) {
      if (v[j] < v[i]) {
        uint16_t t = v[i];
        v[i] = v[j];
        v[j] = t;
      }
    }
  }

  // Median
  return v[n / 2];
}

static void debugFrontendDetect(uint16_t adc, SensorFrontend fe);

static SensorFrontend detectFrontendFromAx() {
  pinMode(FRONTEND_DETECT_PIN, INPUT);
  delay(50);

  uint16_t adc = readAdcMedian(FRONTEND_DETECT_PIN, 24);

  // FE mapping with fixed 10k pull-up on A1:
  // FE1 (1k)   -> Dual
  // FE2 (2.2k) -> Single
  // FE3 (4.7k) -> reserved
  // FE4 (10k)  -> reserved
  SensorFrontend fe;
  if (adc < DETECT_TH_FE1_MAX) {
    fe = FRONTEND_FE1_DUAL;
  } else if (adc < DETECT_TH_FE2_MAX) {
    fe = FRONTEND_FE2_SINGLE;
  } else if (adc < DETECT_TH_FE3_MAX) {
    fe = FRONTEND_FE3_RESERVED;
  } else {
    fe = FRONTEND_FE4_RESERVED;
  }
  debugFrontendDetect(adc, fe);
  return fe;
}

static void debugFrontendDetect(uint16_t adc, SensorFrontend fe) {
#if FRONTEND_DEBUG_SERIAL
  Serial.print(F("[FE] adc="));
  Serial.print(adc);
  Serial.print(F(" -> "));
  switch (fe) {
    case FRONTEND_FE1_DUAL: Serial.println(F("FE1 Dual")); break;
    case FRONTEND_FE2_SINGLE: Serial.println(F("FE2 Single")); break;
    case FRONTEND_FE3_RESERVED: Serial.println(F("FE3 Reserved")); break;
    case FRONTEND_FE4_RESERVED: Serial.println(F("FE4 Reserved")); break;
  }
#endif
}

// =================================================
// Configure sensor pins & glitch filter based on frontend type
// =================================================
void configureSensorFrontend() {
  pinMode(SENSOR_A, INPUT);
  pinMode(SENSOR_B, INPUT);
  MIN_EDGE_SPACING_US = 0;
}

// =================================================
// Sample idle (shutter-closed) logic level on each sensor pin.
// This makes edge capture robust to extra inversion stages on different PCB revisions.
// =================================================
void sampleIdleLevels() {
  // Assumption: when we're in READY (no shutter event), sensors sit at a stable idle level.
  idle_high_s2 = digitalRead(SENSOR_A);
  idle_high_s1 = digitalRead(SENSOR_B);
}

// =================================================
// Shutter speed mapping
// Returns label, writes error_permille; if not matched, error_permille=0x7FFF
// =================================================
const char* shutterLabelFromUs(unsigned long us, char* buf, int16_t* out_err_permille) {
  unsigned long best_err = 0xFFFFFFFF;
  uint8_t best = 0;

  for (uint8_t i = 0; i < SHUTTER_COUNT; i++) {
    uint16_t d = pgm_read_word(&shutter_denoms[i]);
    unsigned long ideal = 1000000UL / d;
    unsigned long err = (us > ideal) ? (us - ideal) : (ideal - us);
    if (err < best_err) {
      best_err = err;
      best = i;
    }
  }

  uint16_t denom = pgm_read_word(&shutter_denoms[best]);
  unsigned long ideal = 1000000UL / denom;

  if (best_err * 1000UL / ideal <= MATCH_THRESHOLD_PERMILLE) {
    long diff = (long)us - (long)ideal;
    long permille = diff * 1000L / (long)ideal;
    if (permille > 32767) permille = 32767;
    if (permille < -32768) permille = -32768;
    *out_err_permille = (int16_t)permille;
    strcpy_P(buf, shutter_labels[best]);
  } else {
    *out_err_permille = 0x7FFF;
    if (us < 1000000UL) sprintf(buf, "~1/%lu", 1000000UL / us);
    else sprintf(buf, "~%lu\"", us / 1000000UL);
  }

  return buf;
}

// =================================================
// UI helpers (moved to Display.cpp)
// =================================================
#include "Display.h"

// =================================================
// Interrupt control
// =================================================
#include "Capture.h"

static inline void markCaptureStarted(unsigned long now_us) {
  if (!capture_started) {
    capture_started = true;
    capture_start_us = now_us;
  }
}

// ISR s2/s1: CHANGE + read level (OPEN/CLOSE based on active_low)
// SENSOR_A -> s2
// SENSOR_B -> s1
// =================================================
// State transitions
// =================================================
void enterError(uint8_t code) {
  ui_state = UI_ERROR;
  error_code = code;
  disableLightISR();  // freeze until RESET
  displayErrorCode(error_code);
}

void resetMeasurement() {
  hist_index = 0;
  hist_filled = 0;

  stability_percent = 0.0f;
  cv_exp_s2_percent = 0.0f;
  cv_v1_percent = 0.0f;
  cv_v2_percent = 0.0f;

  ui_state = UI_READY;
  error_code = 0;
  last_dir = DIR_UNKNOWN;

  noInterrupts();
  s2.t_open = s2.t_close = 0;
  s2.opened = false;
  s1.t_open = s1.t_close = 0;
  s1.opened = false;
  new_result = false;
  capture_done = false;
  capture_started = false;
  capture_start_us = 0;
  last_edge_s2_us = 0;
  last_edge_s1_us = 0;
  interrupts();

  displayModeSplash();
  delay(600);
  displayCentered("READY");
  sampleIdleLevels();
  enableLightISR();
}

// =================================================
// Speed helpers
// =================================================
float speedFromTravelUs(unsigned long travel_us) {
  if (travel_us == 0) return 0.0f;
  float D_m = SENSOR_DISTANCE_MM / 1000.0f;
  float t_s = (float)travel_us / 1000000.0f;
  return D_m / t_s;
}

// =================================================
// Compute CV% with SAMPLE variance (divide by N-1)
// Returns CV%
// =================================================
static float cv_percent_sample_from_array(const float* x, uint8_t n) {
  if (n < 2) return 100.0f;

  float sum = 0.0f;
  for (uint8_t i = 0; i < n; i++) sum += x[i];
  float mean = sum / (float)n;
  if (mean <= 0.0f) return 100.0f;

  float sse = 0.0f;  // sum of squared errors
  for (uint8_t i = 0; i < n; i++) {
    float d = x[i] - mean;
    sse += d * d;
  }

  float variance = sse / (float)(n - 1);  // SAMPLE variance
  if (variance < 0.0f) variance = 0.0f;

  float stddev = sqrt(variance);
  return (stddev / mean) * 100.0f;
}

// =================================================
// Stability calculation
// - SINGLE: CV of exp_s2 (sample variance)
// - DUAL  : CV of v1 and v2 (sample variance), take MAX as overall
// Uses CV% (stability_percent) for HOLD/UNSTABLE decision.
// =================================================
void calculateStability() {
  if (hist_filled < STABLE_COUNT) return;

  // Clear
  cv_exp_s2_percent = 0.0f;
  cv_v1_percent = 0.0f;
  cv_v2_percent = 0.0f;
  stability_percent = 0.0f;

  if (measure_mode == MODE_SINGLE_EXPOSURE) {
    float x[STABLE_COUNT];
    for (uint8_t i = 0; i < STABLE_COUNT; i++) x[i] = (float)expA_hist[i];

    cv_exp_s2_percent = cv_percent_sample_from_array(x, STABLE_COUNT);
    stability_percent = cv_exp_s2_percent;
  } else {
    float v1[STABLE_COUNT];
    float v2[STABLE_COUNT];
    for (uint8_t i = 0; i < STABLE_COUNT; i++) {
      v1[i] = speedFromTravelUs(travel1_hist[i]);
      v2[i] = speedFromTravelUs(travel2_hist[i]);
    }

    cv_v1_percent = cv_percent_sample_from_array(v1, STABLE_COUNT);
    cv_v2_percent = cv_percent_sample_from_array(v2, STABLE_COUNT);

    stability_percent = (cv_v1_percent > cv_v2_percent) ? cv_v1_percent : cv_v2_percent;
  }

  ui_state = (stability_percent <= STABLE_TOLERANCE_PERCENT) ? UI_HOLD : UI_UNSTABLE;
  disableLightISR();  // freeze until RESET
}

// =================================================
// Convert CV% -> "Stability score"
// score = 100 - 3*CV%  (clamped 0..100)
// =================================================
float stabilityScoreFromCV(float cv_percent) {
  float score = 100.0f - 3.0f * cv_percent;
  if (score < 0.0f) score = 0.0f;
  if (score > 100.0f) score = 100.0f;
  return score;
}

// =================================================
// Display: 5-shot table
//   - DUAL  : each row "1/60 v1:xxx v2:xxx", last row "Stability v1:.. v2:.."
//   - SINGLE: each row "1/60 12345us +x.x%", last row "Stability: xx.x%"
// =================================================
// =================================================
// Display: dual realtime (before table is full)
// =================================================
// =================================================
// Display: single realtime (before table is full)
// Keep the same visual structure as the dual realtime screen:
// progress bar + shutter label + measured time + deviation.
// =================================================

// =================================================
// Alignment screen
// Keep visual layout unchanged.
// =================================================
void displayAlignmentScreen() {
  int adc1 = analogRead(ADC1);
  int adc2 = analogRead(ADC2);

  u8g2.firstPage();
  do {
    u8g2.setFont(u8g2_font_6x10_tr);
    u8g2.drawStr(LEFT_MARGIN, 12, "ALIGNMENT");

    // Horizontal display: ADC2 on left, ADC1 on right
    u8g2.setFont(u8g2_font_7x13B_tr);
    char leftBuf[18], rightBuf[18];
    snprintf(leftBuf, sizeof(leftBuf), "L:%d", adc1);
    snprintf(rightBuf, sizeof(rightBuf), "R:%d", adc2);

    int wr = u8g2.getStrWidth(rightBuf);
    u8g2.drawStr(LEFT_MARGIN, 35, leftBuf);
    u8g2.drawStr(128 - RIGHT_MARGIN - wr, 35, rightBuf);

    // center separator
    u8g2.drawVLine(64, 20, 28);

    u8g2.setFont(u8g2_font_6x10_tr);
    u8g2.drawStr(LEFT_MARGIN, 62, "Hold RESET to exit");
  } while (u8g2.nextPage());
}

// =================================================
// Reset button handler
// - Short press: reset measurement
// - Long press : toggle mode (DUAL<->SINGLE)
// - Double click (only when FE=Dual and mode=SINGLE): toggle SINGLE sensor (s1/s2)
// =================================================
bool handleResetButton() {
  static bool last_level = true;  // true = released (pull-up)
  static unsigned long t_last_change = 0;
  static unsigned long t_pressed = 0;
  static bool long_handled = false;

  bool level = digitalRead(BTN_RESET);  // HIGH released, LOW pressed
  unsigned long now_ms = millis();

  if (level != last_level) {
    if (now_ms - t_last_change < BTN_DEBOUNCE_MS) return true;
    t_last_change = now_ms;
    last_level = level;

    if (!level) {
      t_pressed = now_ms;
      long_handled = false;
    } else {
      // released
      if (!long_handled) {
        if (!alignment_mode) {
          // short click in normal mode => reset
          resetMeasurement();
        }
        // short click in alignment mode: do nothing
      }
    }
    return true;
  }

  // long press enters/exits alignment mode
  if (!level && !long_handled) {
    if (now_ms - t_pressed >= BTN_LONGPRESS_MS) {
      long_handled = true;
      if (!alignment_mode) {
        alignment_mode = true;
        disableLightISR();
        setLightSource(true);  // keep light on for alignment
      } else {
        alignment_mode = false;
        resetMeasurement();
      }
      return true;
    }
  }

  return false;
}
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
void loop() {
  handleResetButton();
  handleModeButton();

  if (alignment_mode) {
    displayAlignmentScreen();
    return;
  }

  if (ui_state == UI_ERROR) {
    displayErrorCode(error_code);
    return;
  }
  if (ui_state == UI_HOLD || ui_state == UI_UNSTABLE) {
    updateDisplayTable();
    return;
  }

  // Dual mode timeout: capture started but not completed
  if (measure_mode == MODE_DUAL_CURTAIN && capture_started && !new_result) {
    unsigned long now_us = micros();
    if ((now_us - capture_start_us) > CAPTURE_TIMEOUT_US) {
      uint8_t code = 0;
      noInterrupts();
      bool s2_open_ok = (s2.t_open != 0);
      bool s2_close_ok = (s2.t_close != 0);
      bool s1_open_ok = (s1.t_open != 0);
      bool s1_close_ok = (s1.t_close != 0);
      interrupts();

      if (!s2_open_ok) code = 1;
      else if (!s2_close_ok) code = 2;
      else if (!s1_open_ok) code = 3;
      else if (!s1_close_ok) code = 4;
      else code = 5;

      enterError(code);
      return;
    }
  }

  if (!new_result) return;

  // Copy timestamps atomically
  unsigned long s2_open, s2_close, s1_open, s1_close;
  noInterrupts();
  s2_open = s2.t_open;
  s2_close = s2.t_close;
  s1_open = s1.t_open;
  s1_close = s1.t_close;

  new_result = false;
  capture_done = false;
  capture_started = false;
  capture_start_us = 0;

  // Clear for next shot
  s2.t_open = s2.t_close = 0;
  s2.opened = false;
  s1.t_open = s1.t_close = 0;
  s1.opened = false;
  interrupts();

  // Pick the active sensor for SINGLE mode
  unsigned long single_open = singleUsesS1() ? s1_open : s2_open;
  unsigned long single_close = singleUsesS1() ? s1_close : s2_close;

  // Validate the primary exposure (SINGLE: selected sensor, DUAL: s2)
  unsigned long exp_s2 = 0;
  if (measure_mode == MODE_SINGLE_EXPOSURE) {
    if (single_close <= single_open) {
      enterError(5);
      return;
    }
    exp_s2 = single_close - single_open;
  } else {
    if (s2_close <= s2_open) {
      enterError(5);
      return;
    }
    exp_s2 = s2_close - s2_open;
  }

  if (exp_s2 < MIN_VALID_EXPOSURE || exp_s2 > MAX_VALID_EXPOSURE) return;

  unsigned long exp_s1 = 0;
  unsigned long travel1 = 0, travel2 = 0;
  int16_t err_s2 = 0x7FFF, err_s1 = 0x7FFF;

  shutterLabelFromUs(exp_s2, g_label, &err_s2);

  TravelDirection dir = DIR_UNKNOWN;

  if (measure_mode == MODE_DUAL_CURTAIN) {
    // Validate s1
    if (s1_close <= s1_open) {
      enterError(5);
      return;
    }

    exp_s1 = s1_close - s1_open;
    if (exp_s1 < MIN_VALID_EXPOSURE || exp_s1 > MAX_VALID_EXPOSURE) return;

    // --------- AUTO direction detect ----------
    long dOpen = (long)s1_open - (long)s2_open;
    long dClose = (long)s1_close - (long)s2_close;

    if (dOpen == 0) {
      enterError(5);
      return;
    }

    // Determine direction by OPEN edge order
    dir = (dOpen > 0) ? DIR_S2_TO_S1 : DIR_S1_TO_S2;

    // Travel times are absolute (direction-insensitive)
    travel1 = (unsigned long)labs(dOpen);
    travel2 = (unsigned long)labs(dClose);

    // Consistency check: CLOSE edges must keep same order as OPEN edges
    if ((dClose == 0) || ((dOpen > 0) != (dClose > 0))) {
      enterError(5);
      return;
    }

    // Error of s1 exposure relative to standard shutter speeds (optional)
    shutterLabelFromUs(exp_s1, g_tmp, &err_s1);
  }

  // Save direction (for display)
  last_dir = dir;

  // Store history (s2->A arrays, s1->B arrays)
  expA_hist[hist_index] = exp_s2;
  errA_hist[hist_index] = err_s2;

  expB_hist[hist_index] = exp_s1;
  errB_hist[hist_index] = err_s1;

  travel1_hist[hist_index] = travel1;
  travel2_hist[hist_index] = travel2;

  hist_index++;
  if (hist_index >= STABLE_COUNT) hist_index = 0;
  if (hist_filled < STABLE_COUNT) hist_filled++;

  // After 5 samples -> HOLD or UNSTABLE (both freeze until RESET)
  if (hist_filled == STABLE_COUNT) {
    calculateStability();
    updateDisplayTable();
    return;
  }

  // Real-time display
  if (measure_mode == MODE_DUAL_CURTAIN) {
    updateDisplayDual(exp_s2, err_s2, exp_s1, err_s1, travel1, travel2, dir);
  } else {
    // Single mode realtime screen matches the dual layout
    updateDisplaySingle(exp_s2, err_s2, singleUsesS1());
  }
}

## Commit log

2026-02-05 remove hardware
    [BOM.xlsx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]
2026-02-26 update code according to v1.0.3 hardware, functionalies are equivalent to v0.9.2 code. 1. Add 74AHC14 display 2. adjust ID/CFG resistor and adc value, 3. allow user to select sensor for single mode
2026-03-08 Refactor README to update file name
    Renamed the main Arduino file for clarity.
2026-03-08 Add Hardware 1.0.3 files
    [BOM v1.0.3.csv]
2026-11-03 docs: add Nano v1.0.0 user guide
    Add the current Nano edition guide for website and PDF publishing.
